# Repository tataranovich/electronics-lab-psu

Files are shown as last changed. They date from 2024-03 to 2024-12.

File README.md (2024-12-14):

# Lab PSU

Linear power supply with 5 fixed outputs (+12V, +5V, +3.3V, -5V, -12V).

**Features:**

- 5 linear outputs: +12V, +5V, +3.3V, -5V, -12V
- Up to 1A of current for positive and negative rail
- Current indication on both rails
- Low noise (25mV peak-peak on negative rail, 15mV peak-peak on positive rail)
- Temperature controlled fan

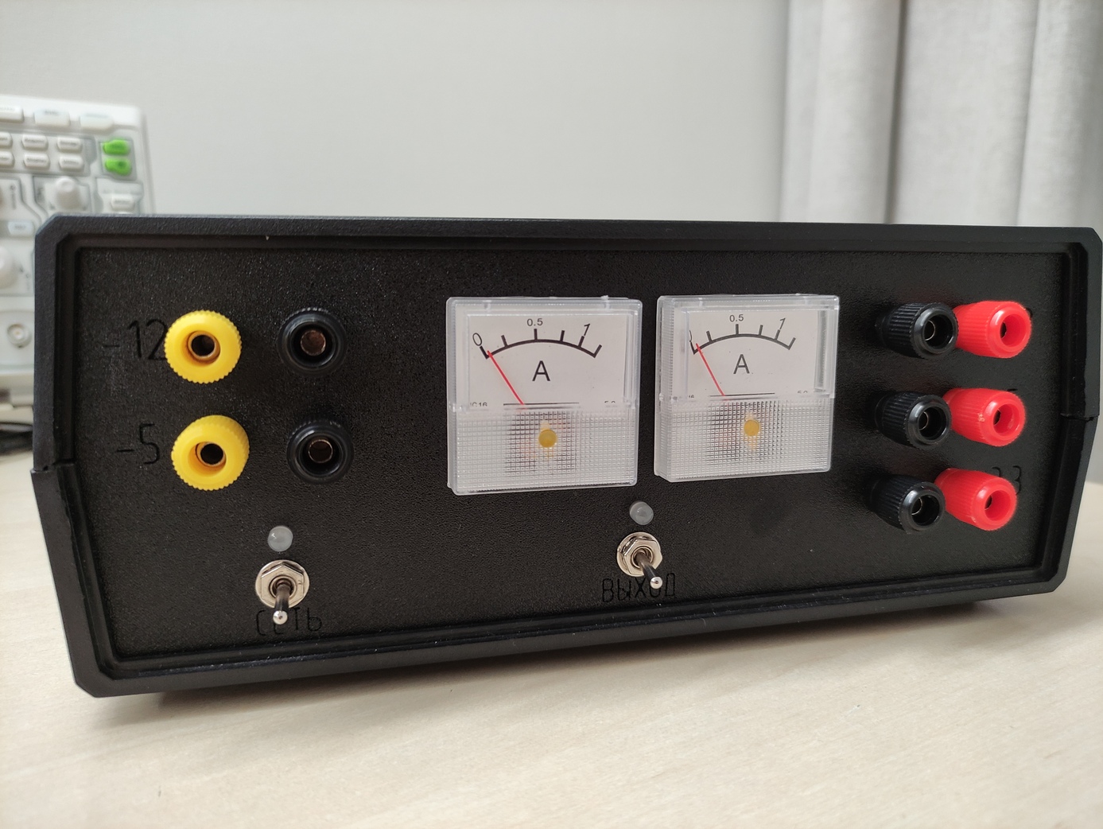
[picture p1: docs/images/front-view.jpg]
Front view


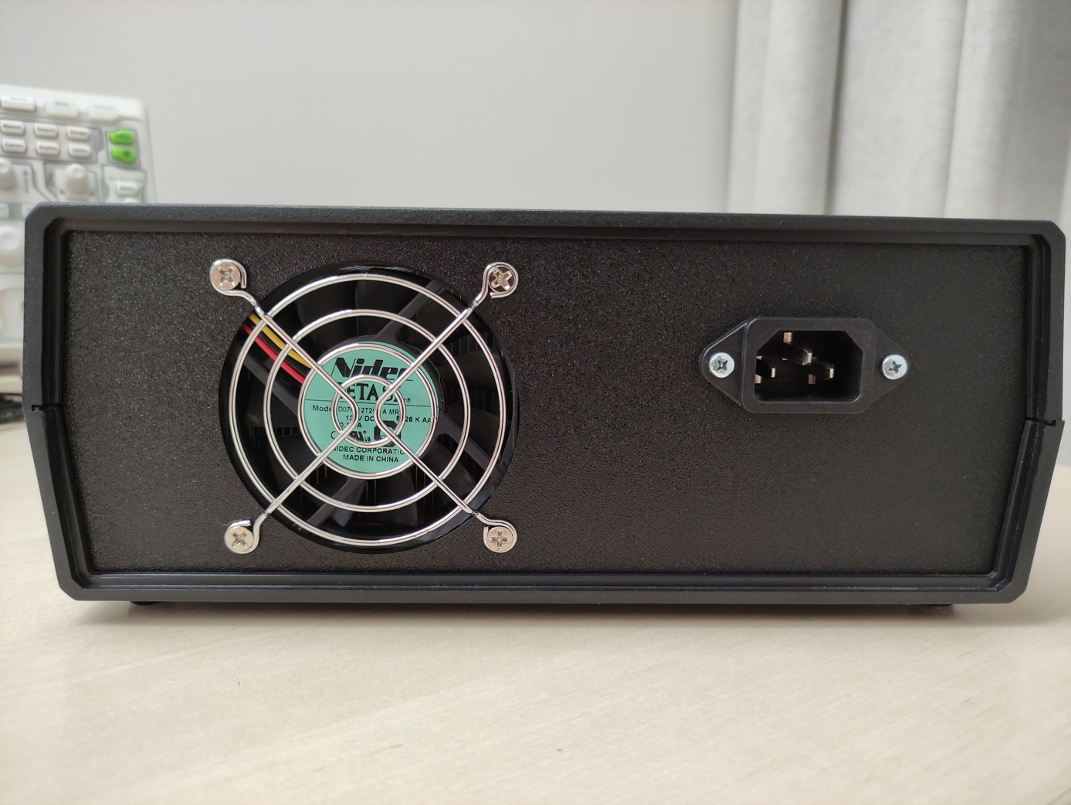
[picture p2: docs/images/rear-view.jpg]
Rear view


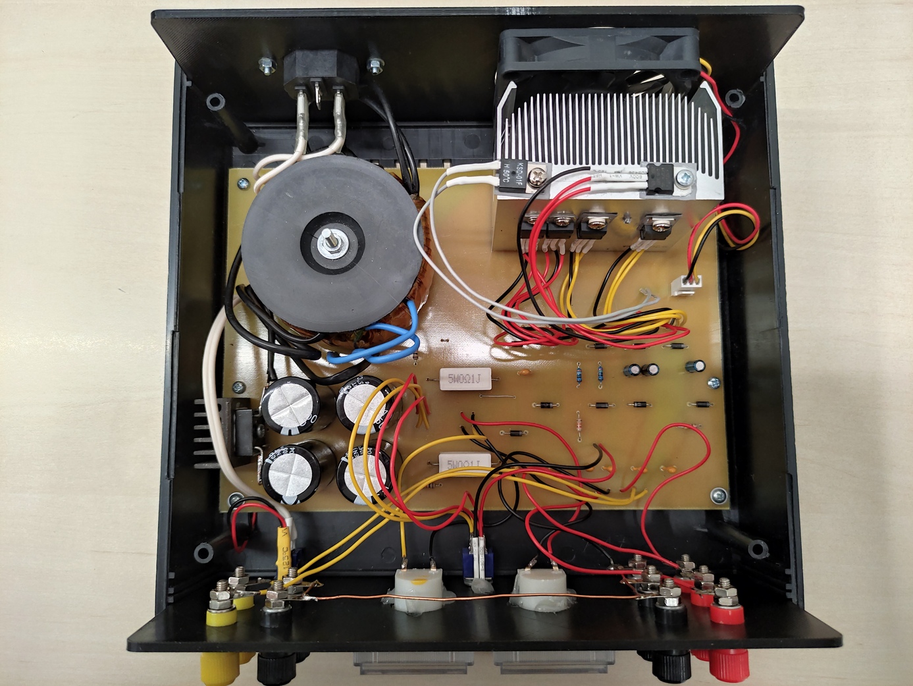
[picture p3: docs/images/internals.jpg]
Internals


**Assembly notes**

- Power supply case: Kradex Z17
- AC transformer: 40W toroid with 18V secondary
- Ammeters: 91C16 with [custom scale](./scale/91C16%20scale.svg) created using [Scale Master](https://soulmare.github.io/scale_master/)
- Cooling: CMDK8-7I52D-A5-GP or equivalent (70mm fan)
- [Schematic and PCB](./kicad) created using KiCad
- [Case panels](./panels) created using LibreCad and FreeCad

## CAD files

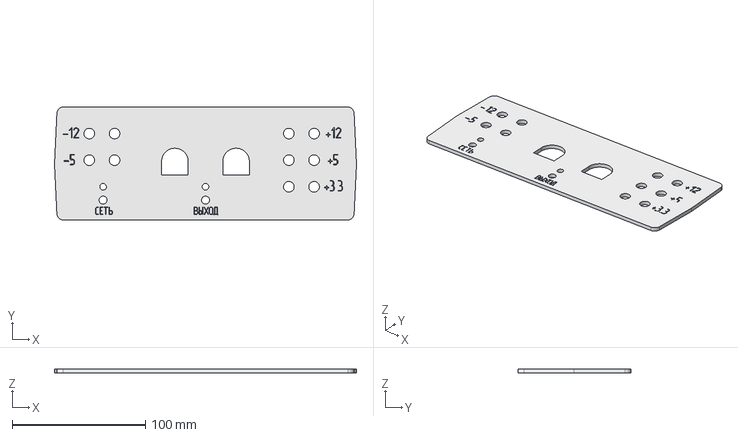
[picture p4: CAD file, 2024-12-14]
panels/kradex-z17-front-panel.FCStd
227.0 x 85.0 x 3.00 mm

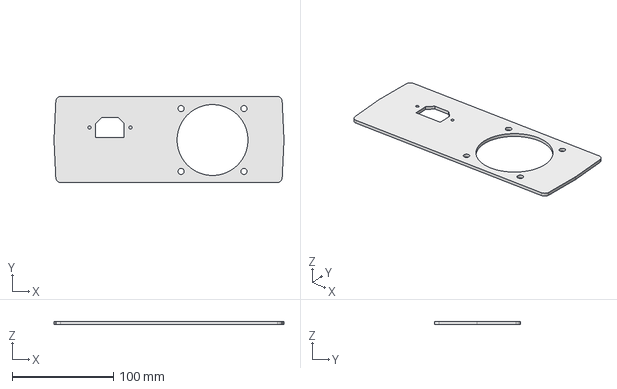
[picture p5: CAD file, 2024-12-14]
panels/kradex-z17-back-panel.FCStd
227.0 x 85.0 x 3.00 mm

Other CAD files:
panels/kradex-z17-back-panel.dxf
panels/kradex-z17-back-panel.stl
panels/kradex-z17-front-panel.dxf
panels/kradex-z17-front-panel.stl

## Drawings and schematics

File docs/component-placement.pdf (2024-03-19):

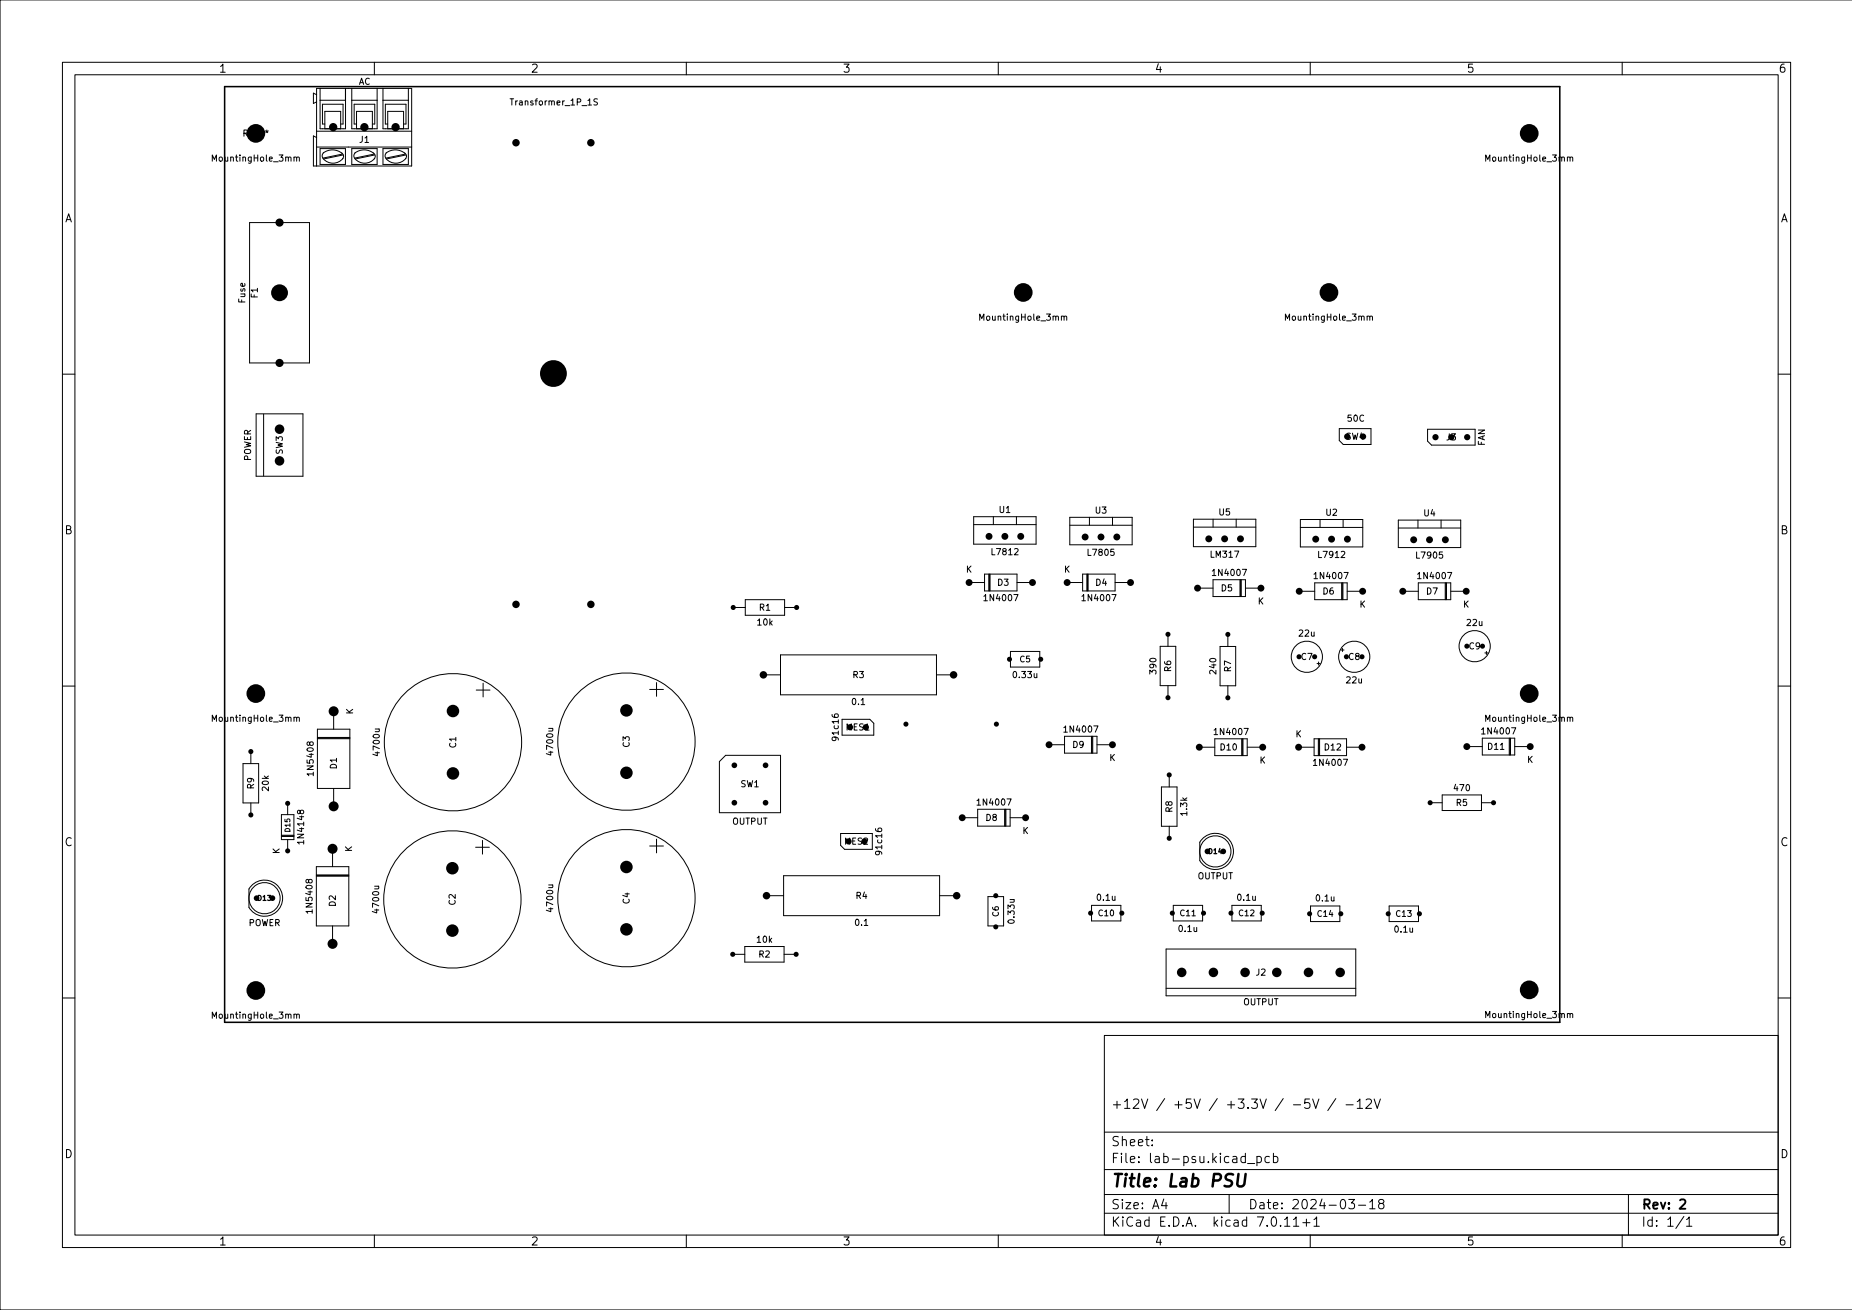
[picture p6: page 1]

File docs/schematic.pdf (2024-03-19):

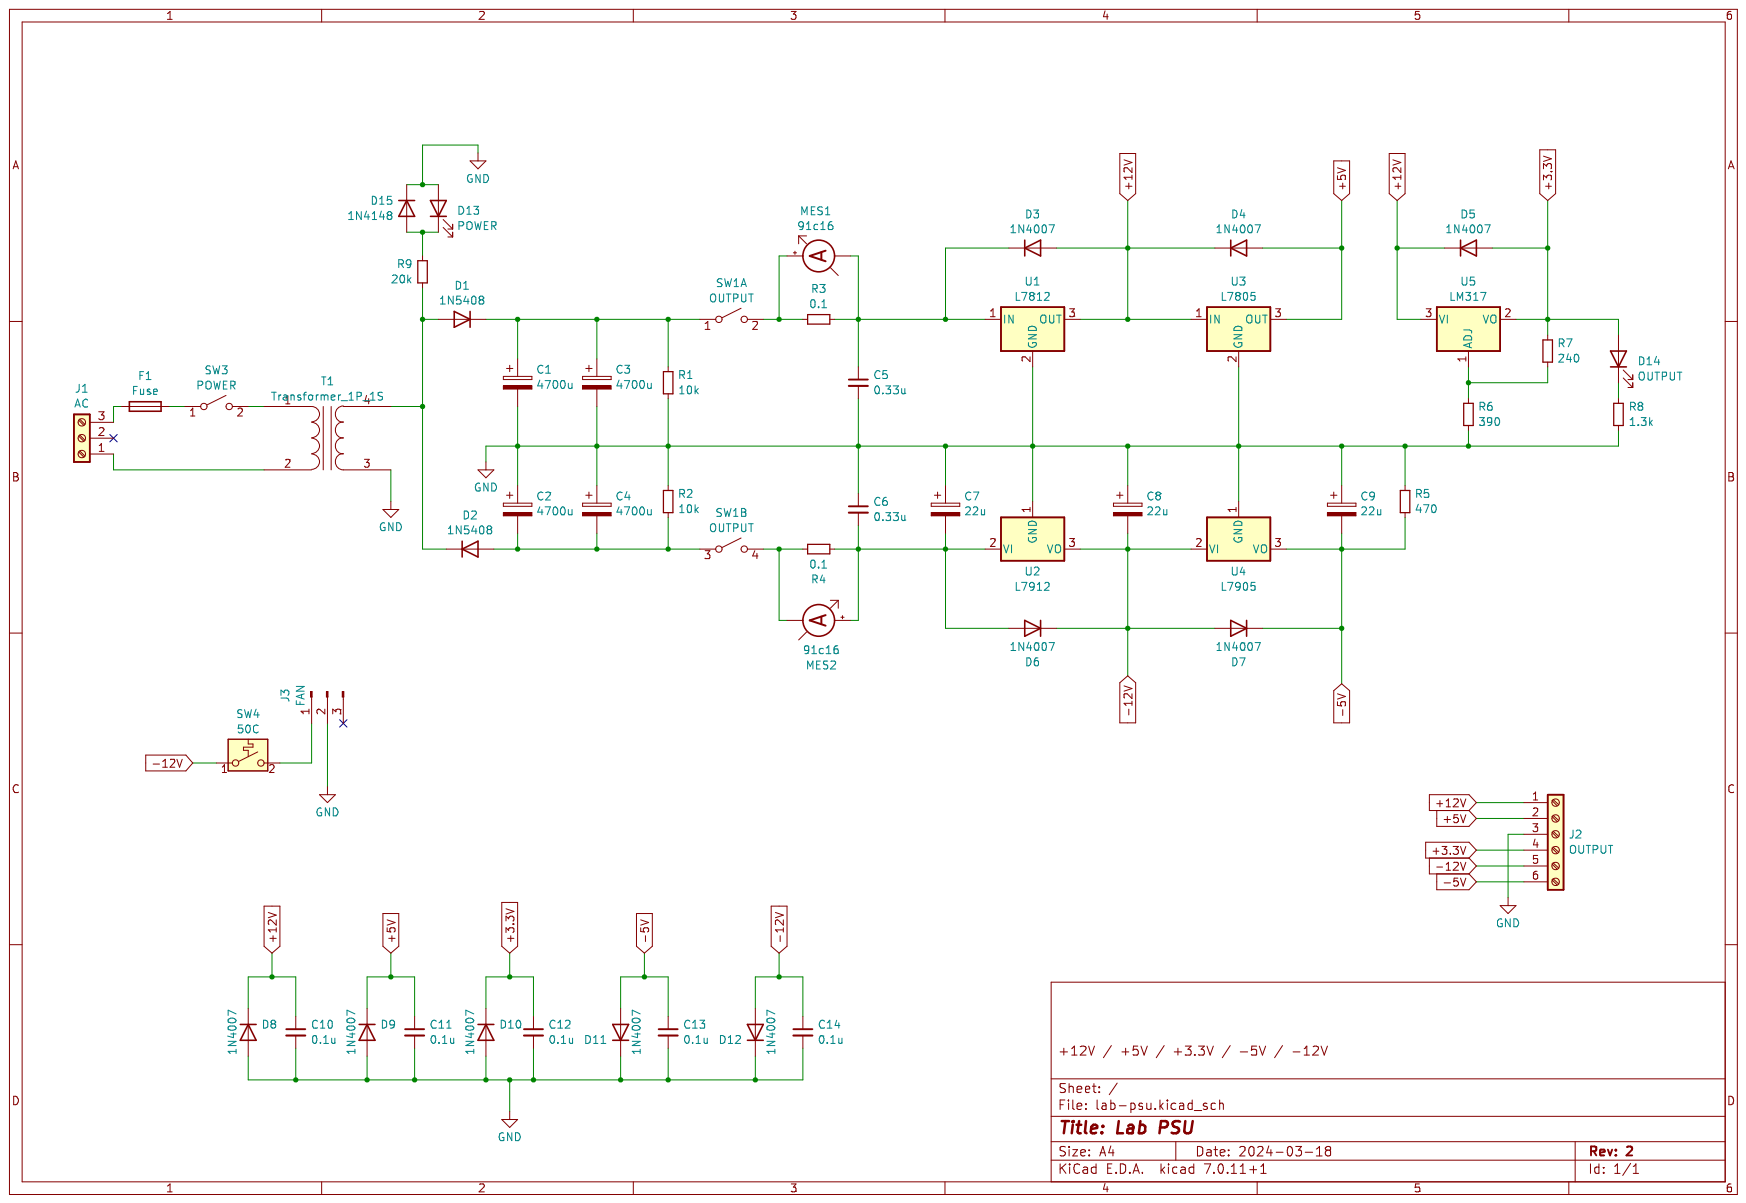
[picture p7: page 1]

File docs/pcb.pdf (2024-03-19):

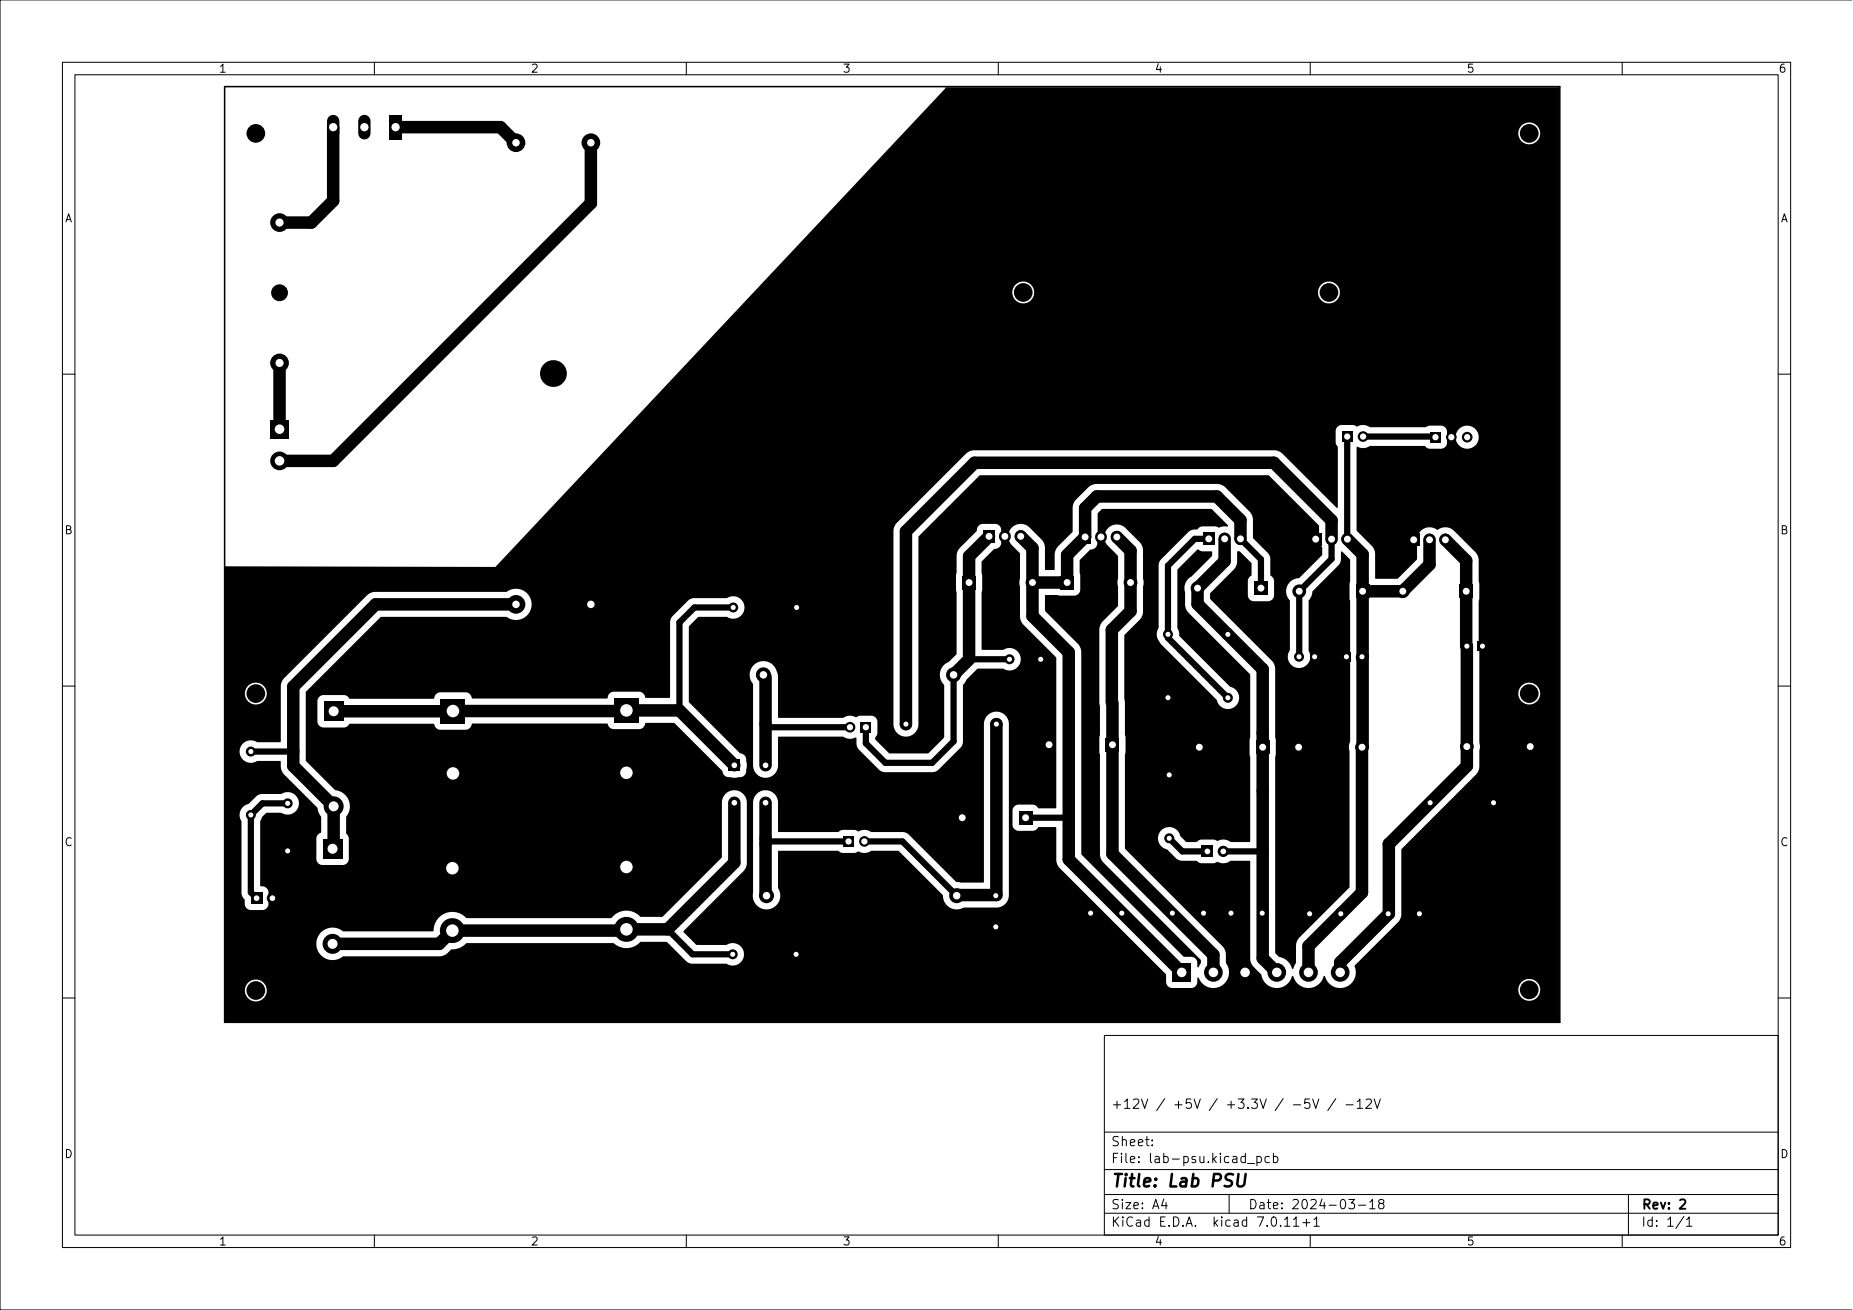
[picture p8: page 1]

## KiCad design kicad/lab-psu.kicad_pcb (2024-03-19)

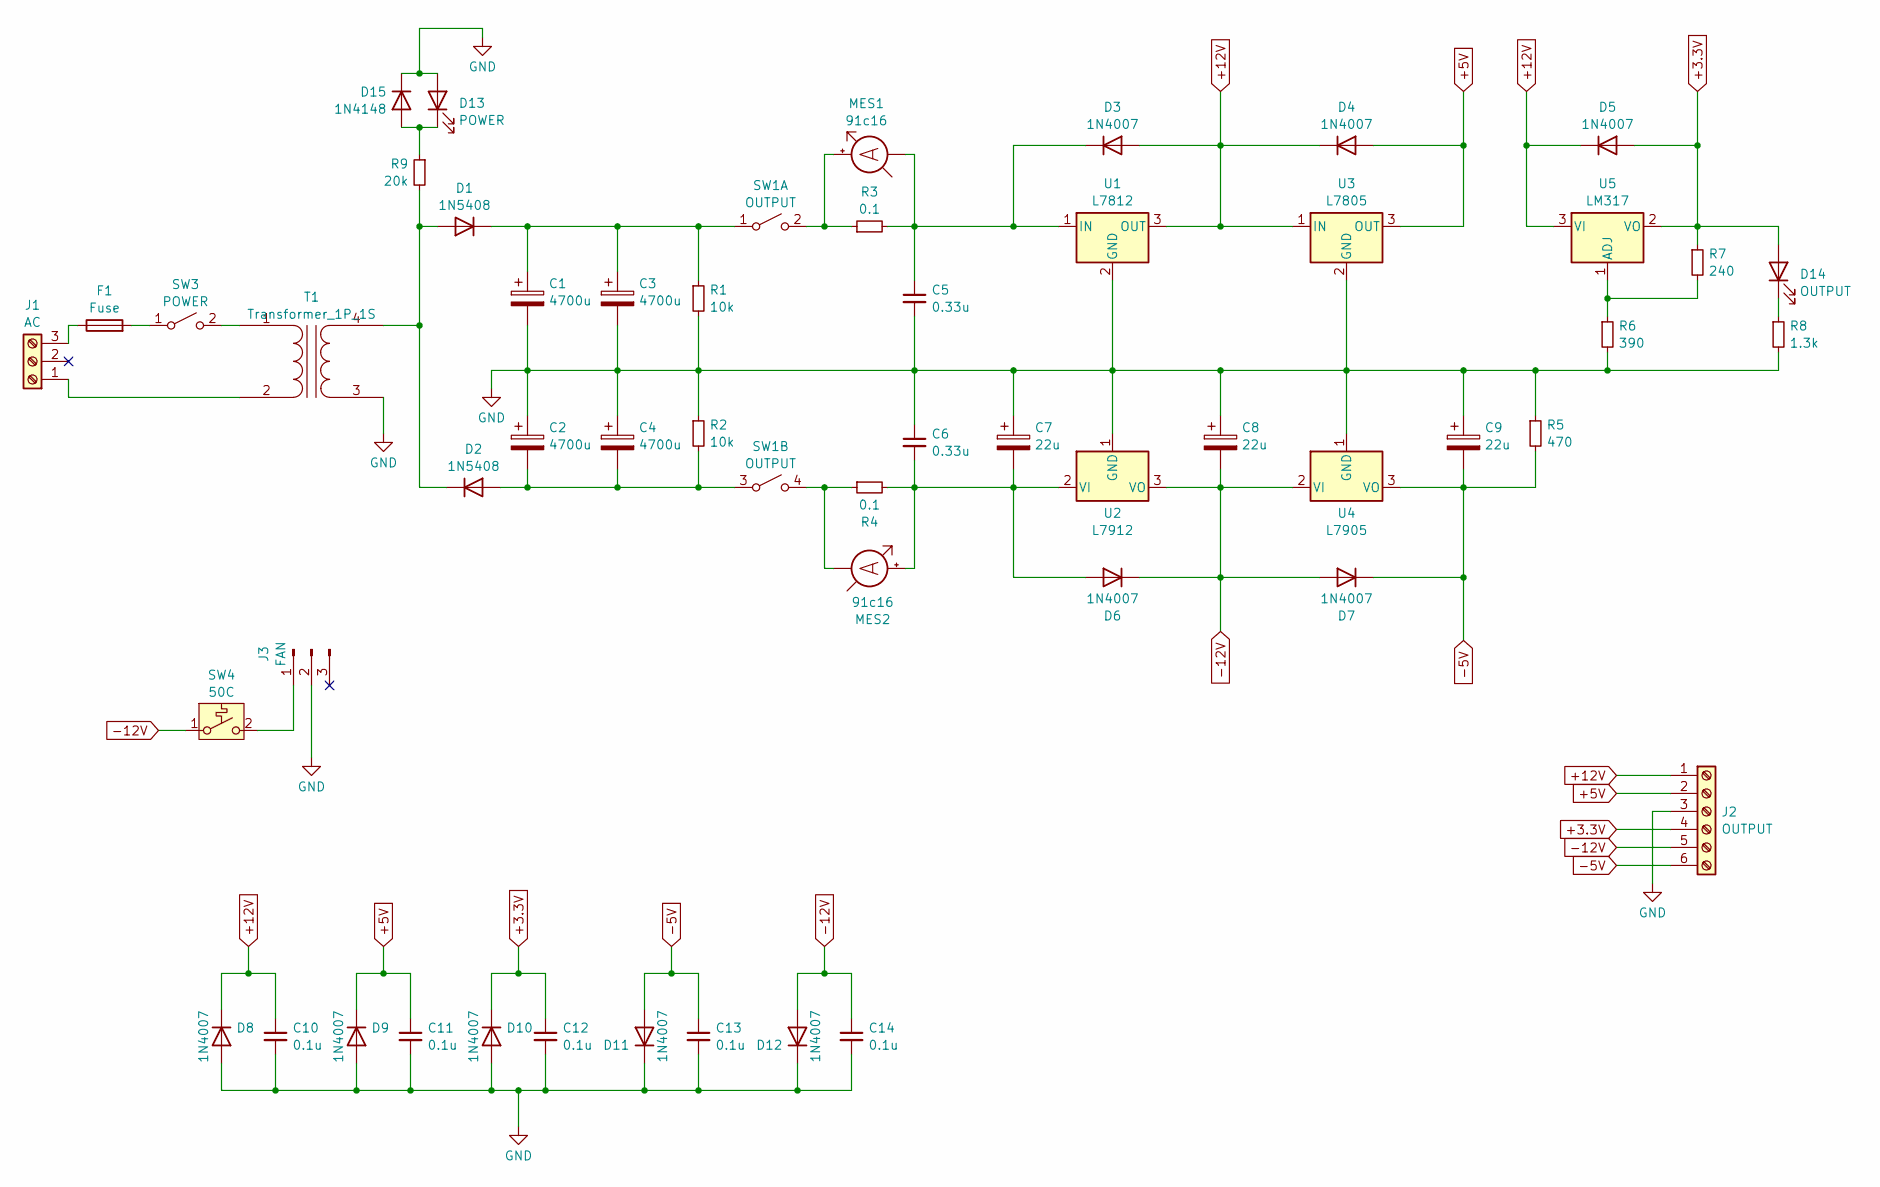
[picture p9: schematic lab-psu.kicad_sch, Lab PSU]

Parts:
C1, C2, C3, C4: 4700u; CP_Radial_D22.0mm_P10.00mm_SnapIn
C5, C6: 0.33u; C_Disc_D4.7mm_W2.5mm_P5.00mm
C7, C8, C9: 22u; CP_Radial_D5.0mm_P2.50mm
C10, C11, C12, C13, C14: 0.1u; C_Disc_D4.7mm_W2.5mm_P5.00mm
D1, D2: 1N5408; D_DO-201AD_P15.24mm_Horizontal
D3, D4, D5, D6, D7, D8, D9, D10, D11, D12: 1N4007; D_DO-41_SOD81_P10.16mm_Horizontal
D13: POWER; LED_D5.0mm
D14: OUTPUT; LED_D5.0mm
D15: 1N4148; D_DO-35_SOD27_P7.62mm_Horizontal
F1: Fuse; Fuseholder_Cylinder-5x20mm_Schurter_0031_8201_Horizontal_Op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
J1: AC; TerminalBlock_Altech_AK300-3_P5.00mm
J2: OUTPUT; TerminalBlock_bornier-6_P5.08mm
J3: FAN; PinHeader_1x03_P2.54mm_Vertical
MES1, MES2: 91c16; PinHeader_1x02_P2.54mm_Vertical
R1, R2: 10k; R_Axial_DIN0207_L6.3mm_D2.5mm_P10.16mm_Horizontal
R3, R4: 0.1; R_Axial_Power_L25.0mm_W6.4mm_P30.48mm
R5: 470; R_Axial_DIN0207_L6.3mm_D2.5mm_P10.16mm_Horizontal
R6: 390; R_Axial_DIN0207_L6.3mm_D2.5mm_P10.16mm_Horizontal
R7: 240; R_Axial_DIN0207_L6.3mm_D2.5mm_P10.16mm_Horizontal
R8: 1.3k; R_Axial_DIN0207_L6.3mm_D2.5mm_P10.16mm_Horizontal
R9: 20k; R_Axial_DIN0207_L6.3mm_D2.5mm_P10.16mm_Horizontal
SW1: OUTPUT; SW_Push_2P1T_Toggle_CK_PVA1xxH4xxxxxxV2
SW3: POWER; TerminalBlock_bornier-2_P5.08mm
SW4: 50C; PinHeader_1x02_P2.54mm_Vertical
T1: Transformer_1P_1S; Transformer_Toroid_Tapped_Horizontal_D70.0mm
U1: L7812; TO-220-3_Vertical
U2: L7912; TO-220-3_Vertical
U3: L7805; TO-220-3_Vertical
U4: L7905; TO-220-3_Vertical
U5: LM317; TO-220-3_Vertical

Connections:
+3.3V: C12.1, D5.2 (A), D10.1 (K), D14.2 (A), J2.4, R7.1, U5.2 (VO)
+5V: C11.1, D4.2 (A), D9.1 (K), J2.2, U3.3 (OUT)
+12V: C10.1, D3.2 (A), D4.1 (K), D5.1 (K), D8.1 (K), J2.1, U1.3 (OUT), U3.1 (IN), U5.3 (VI)
-5V: C9.2, C13.1, D7.1 (K), D11.2 (A), J2.6, R5.2, U4.3 (VO)
-12V: C8.2, C14.1, D6.1 (K), D7.2 (A), D12.2 (A), J2.5, SW4.1 (A), U2.3 (VO), U4.2 (VI)
GND: C1.2, C2.1, C3.2, C4.1, C5.2, C6.1, C7.1, C8.1, C9.1, C10.2, C11.2, C12.2, C13.2, C14.2, D8.2 (A), D9.2 (A), D10.2 (A), D11.1 (K), D12.1 (K), D13.2 (A), D15.1 (K), J2.3, J3.2, R1.2, R2.1, R5.1, R6.2, R8.2, T1.3 (SA), U1.2 (GND), U2.1 (GND), U3.2 (GND), U4.1 (GND)
unnamed: D1.2 (A), D2.1 (K), R9.2, T1.4 (SB)
unnamed: C1.1, C3.1, D1.1 (K), R1.1, SW1.1 (A)
unnamed: C2.2, C4.2, D2.2 (A), R2.2, SW1.3 (A)
unnamed: C5.1, D3.1 (K), MES1.1 (-), R3.2, U1.1 (IN)
unnamed: C6.2, C7.2, D6.2 (A), MES2.2 (+), R4.2, U2.2 (VI)
unnamed: D13.1 (K), D15.2 (A), R9.1
unnamed: D14.1 (K), R8.1
unnamed: J1.1, T1.2 (AB)
unnamed: F1.1, J1.3
unnamed: J3.1, SW4.2 (B)
unnamed: MES1.2 (+), R3.1, SW1.2 (B)
unnamed: MES2.1 (-), R4.1, SW1.4 (B)
unnamed: F1.2, SW3.1 (A)
unnamed: SW3.2 (B), T1.1 (AA)
unnamed: R6.1, R7.2, U5.1 (ADJ)

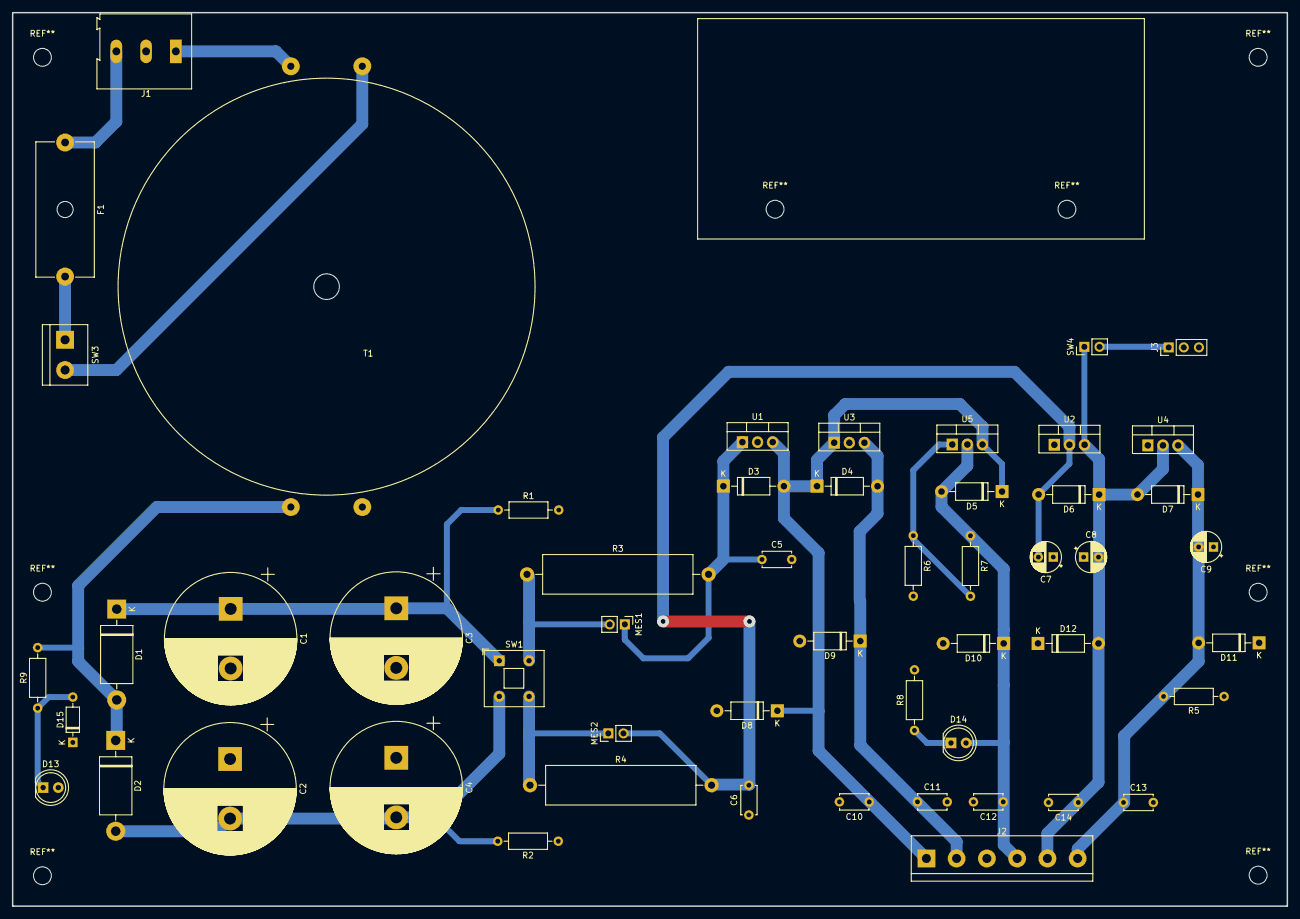
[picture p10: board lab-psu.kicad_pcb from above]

Board: 2 copper layers, 214.0 x 150.0 mm, 53 parts (0 on the bottom side), 21 nets.

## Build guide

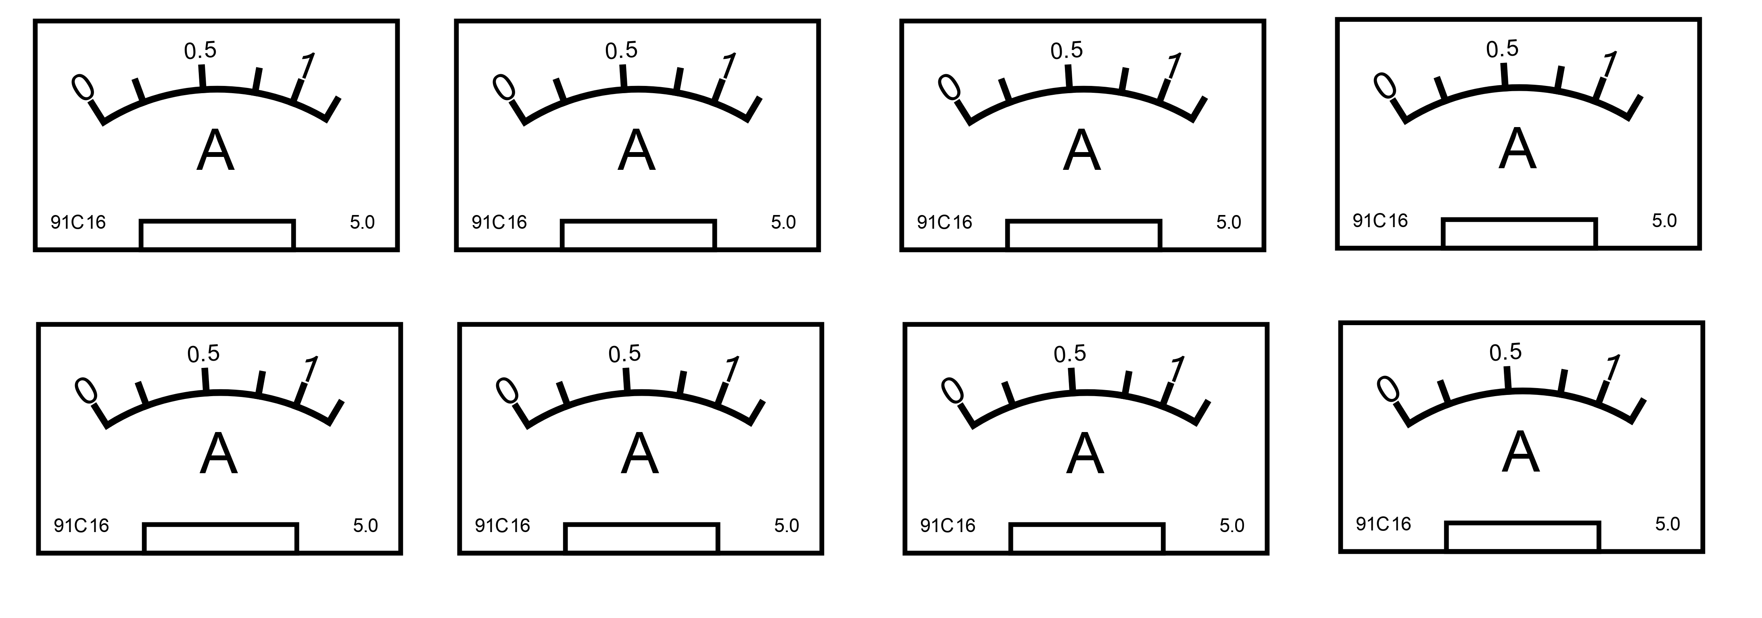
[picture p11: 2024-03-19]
scale/91C16 scale - print.png

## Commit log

2024-03-19 Lab PSU revision 2
    [kradex-z17-back-panel.dxf, kradex-z17-front-panel.dxf, lab-psu.kicad_pcb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]
2024-12-14 Refactor front panel, add STL files for 3D printing
    [kradex-z17-back-panel.FCStd, kradex-z17-back-panel.dxf, kradex-z17-back-panel.stl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]
